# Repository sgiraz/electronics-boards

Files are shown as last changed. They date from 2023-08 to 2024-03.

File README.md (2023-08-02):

Electronics Boards
==================

This is the `electronics-boards` repository, containing all the electronic boards developed for study and DIY purposes.

Each board has an own folder where there are schematic, layout, firmware, simulations, documents, photos, configuration files, etc.

The board folders follow these rules:
- foldername **name of the board** 
- admitted subfolders:
   - **docs** folder contains documents
      - **datasheet** folder contains useful datasheet
      - **manuals** folder contains reference manual
   - **output** folder contains files for the production of the PCB and board (Gerber files, BOM, PCB Notes, etc.)
   - **kicad** folder contains the KiCad project
   - **pics** folder contains useful photos and videos of pcb, board, setup
   - **sw** folder contains the firmware useful for the board (test, normal operation, etc)
   
Note: folders and files must be named in lowercase

## Git LFS remark
This repository exploits the Git Large File Support ([LFS][1]) to handle the binary files.
To download the binary files, follow the GitHub [instructions][2]. To configure Git LFS, follow these [instructions][3].

[1]: https://git-lfs.github.com/
[2]: https://help.github.com/articles/installing-git-large-file-storage/
[3]: https://help.github.com/en/github/managing-large-files/configuring-git-large-file-storage

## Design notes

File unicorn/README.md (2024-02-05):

# The Unicorn Board

## Overview

The Unicorn Board, designed by Simone Girardi in 2022, is a compact, Arduino-like programmable board. It's equipped with service LEDs for TX and RX, making it a versatile tool for various microcontroller projects.

Unicorn Board

## Features

- **ATmega328P Microcontroller**: Powers your projects.
- **16MHz Crystal Oscillator**: Provides a stable clock signal.
- **Input Voltage**: Accepts an external power supply ranging from 7V to 12V.
- **7805 Voltage Regulator**: Ensures a steady 5V supply to the microcontroller and other components.
- **TX and RX LEDs**: Offer visual feedback for data transmission and reception.
- **ISP Header**: Facilitates easy programming.
- **Reset Button**: Allows for easy resetting.

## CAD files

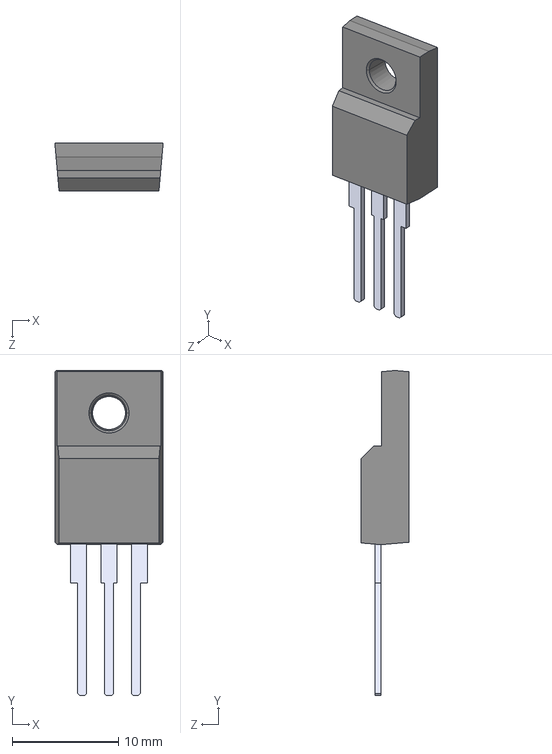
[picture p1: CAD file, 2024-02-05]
unicorn/kicad/components/L7805/L7805.step
10.2 x 30.6 x 4.50 mm

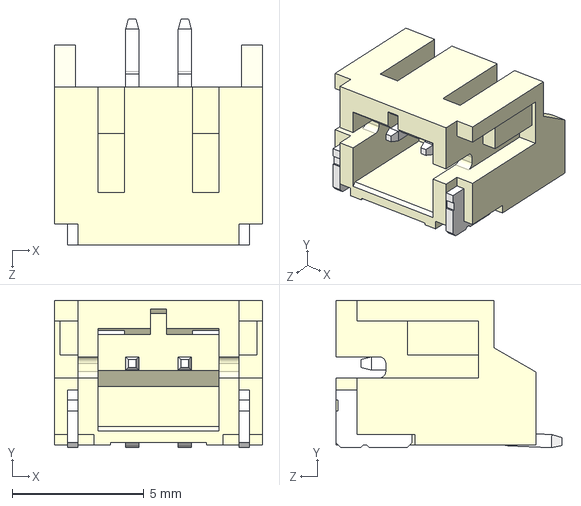
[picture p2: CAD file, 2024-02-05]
unicorn/kicad/components/S2B_PH_SM4_TB/S2B-PH-SM4-TB.step
7.90 x 5.60 x 8.60 mm

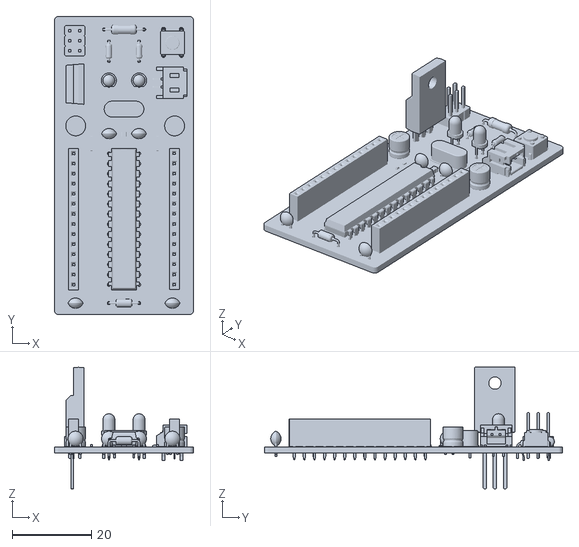
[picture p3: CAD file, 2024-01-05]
unicorn/unicorn.stl
35.0 x 75.0 x 30.6

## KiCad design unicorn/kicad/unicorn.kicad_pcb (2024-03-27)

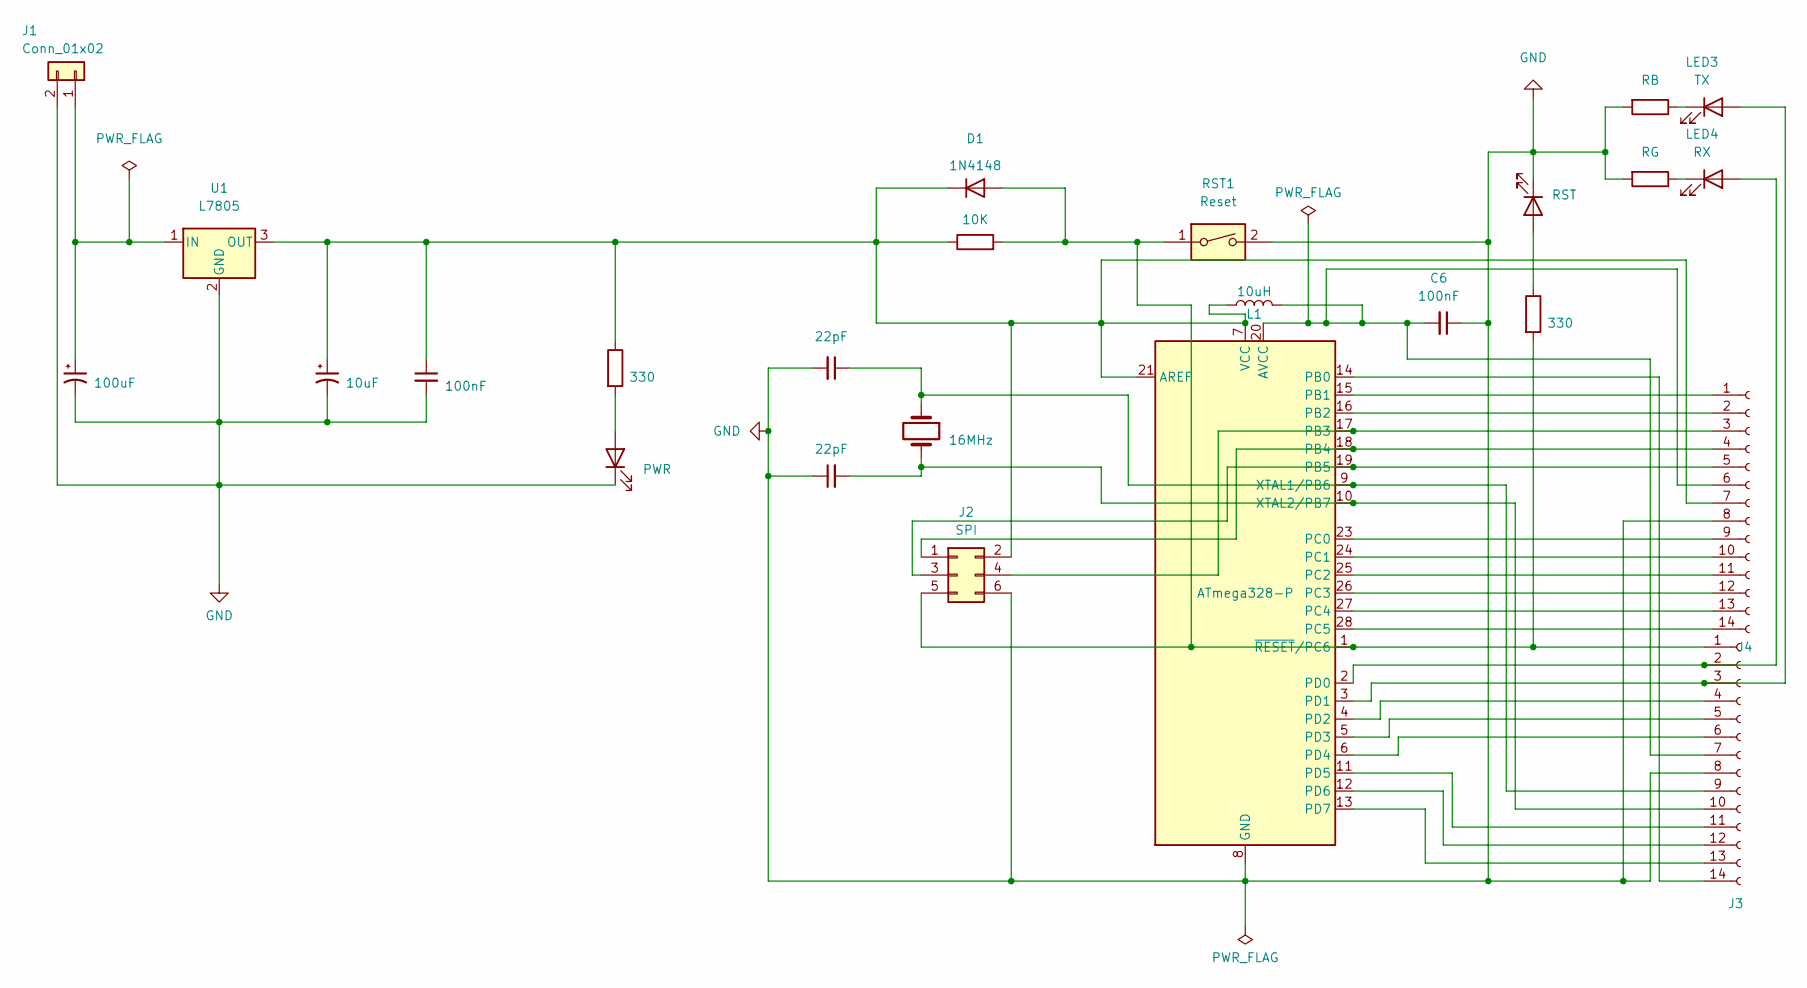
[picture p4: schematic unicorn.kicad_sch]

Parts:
C1: 100uF; CP_Radial_D5.0mm_P2.00mm
C2: 10uF; CP_Radial_D5.0mm_P2.00mm
C3, C6: 100nF; C_Disc_D3.8mm_W2.6mm_P2.50mm
C4, C5: 22pF; C_Disc_D3.8mm_W2.6mm_P2.50mm
Crystal1: 16MHz; Crystal_HC49-4H_Vertical
D1: 1N4148; D_DO-35_SOD27_P7.62mm_Horizontal
J1: Conn_01x02; JST_S2B-PH-SM4-TB
J2: SPI; PinHeader_2x03_P2.54mm_Vertical
J3, J4: Conn_01x14_Female; PinSocket_1x14_P2.54mm_Vertical
L1: 10uH; L_0805_2012Metric_Pad1.05x1.20mm_HandSolder
LED1: PWR; LED_D3.0mm
LED2: RST; LED_D3.0mm
LED3: TX; LED_0402_1005Metric
LED4: RX; LED_0402_1005Metric
R1, R3: 330; R_Axial_DIN0204_L3.6mm_D1.6mm_P5.08mm_Horizontal
R2: 10K; R_Axial_DIN0207_L6.3mm_D2.5mm_P10.16mm_Horizontal
R4: RB; R_0402_1005Metric
R5: RG; R_0402_1005Metric
RST1: Reset; SW_PUSH_6mm
U1: L7805; TO255P1020X450X2000-3
U2: ATmega328-P; DIP-28_W7.62mm

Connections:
GND: C1.2, C2.2, C3.2, C4.2, C5.1, C6.1, J1.2, J2.6, J3.8, J4.8, LED1.1 (K), LED2.1 (K), R4.2, R5.2, RST1.2, U1.2 (GND), U2.8 (GND), U2.22 (GND)
unnamed: D1.2 (A), J2.5, J3.1, R2.2, R3.2, RST1.1, U2.1 (~RESET/PC6)
unnamed: C2.1, C3.1, D1.1 (K), J2.2, J4.7, L1.1, R1.1, R2.1, U1.3 (OUT), U2.7 (VCC), U2.21 (AREF)
unnamed: C1.1, J1.1, U1.1 (IN)
unnamed: J2.1, J4.4, U2.18 (PB4)
unnamed: J2.3, J4.5, U2.19 (PB5)
unnamed: J2.4, J4.3, U2.17 (PB3)
unnamed: J3.2, LED4.2 (A), U2.2 (PD0)
unnamed: J3.3, LED3.2 (A), U2.3 (PD1)
unnamed: J3.4, U2.4 (PD2)
unnamed: J3.5, U2.5 (PD3)
unnamed: J3.6, U2.6 (PD4)
unnamed: C6.2, J3.7, J4.6, L1.2, U2.20 (AVCC)
unnamed: C4.1, Crystal1.1, J3.9, U2.9 (XTAL1/PB6)
unnamed: C5.2, Crystal1.2, J3.10, U2.10 (XTAL2/PB7)
unnamed: J3.11, U2.11 (PD5)
unnamed: J3.12, U2.12 (PD6)
unnamed: J3.13, U2.13 (PD7)
unnamed: J3.14, U2.14 (PB0)
unnamed: J4.1, U2.15 (PB1)
unnamed: J4.2, U2.16 (PB2)
unnamed: J4.9, U2.23 (PC0)
unnamed: J4.10, U2.24 (PC1)
unnamed: J4.11, U2.25 (PC2)
unnamed: J4.12, U2.26 (PC3)
unnamed: J4.13, U2.27 (PC4)
unnamed: J4.14, U2.28 (PC5)
unnamed: LED1.2 (A), R1.2
unnamed: LED2.2 (A), R3.1
unnamed: LED3.1 (K), R4.1
unnamed: LED4.1 (K), R5.1

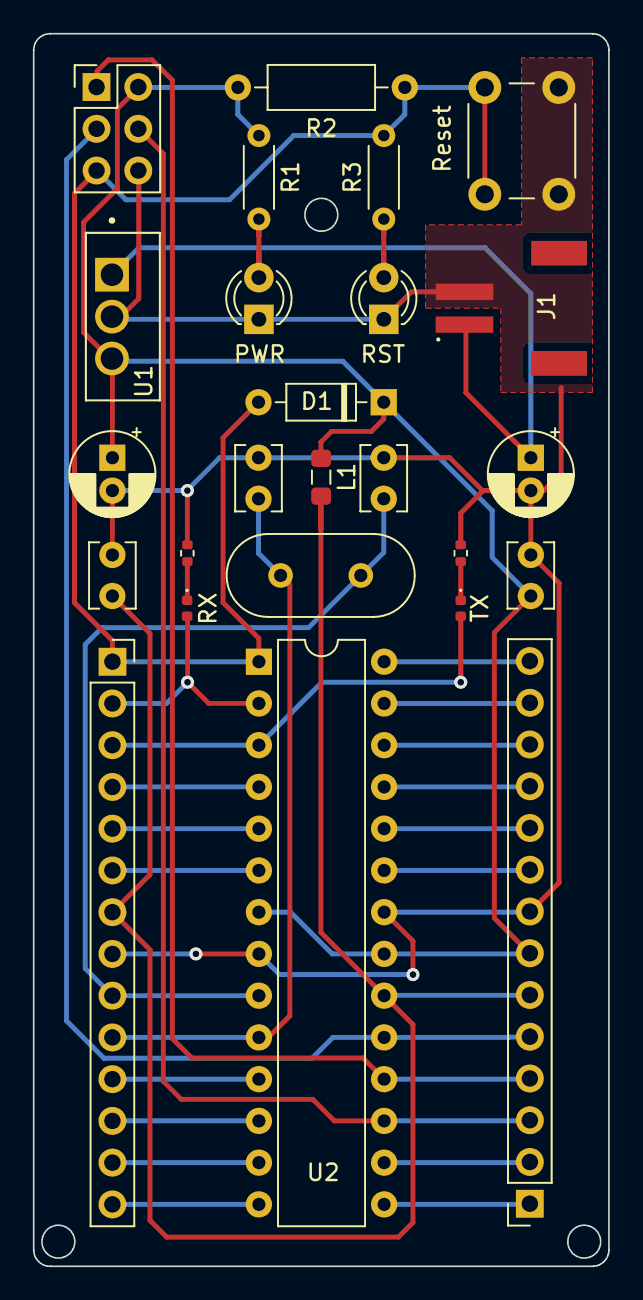
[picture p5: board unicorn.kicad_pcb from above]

Board: 2 copper layers, 35.0 x 75.0 mm, 25 parts (0 on the bottom side), 31 nets.

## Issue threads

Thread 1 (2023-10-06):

Unicorn: Add fixing holes

sgiraz, 2023-10-06:
### Task description

For a simpler mounting we have to create a fixing holes directly on the board.

### Definition of Done

- [ ] holes done and projects updated

sgiraz, 2024-03-03:
Mounting hole applied w/ a diameter M2:

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

>[!Important]
>Before submit a new build of the unicorn board we have to look for the proper screws (see https://it.rs-online.com/web/c/ferramenta/viti-e-bulloni/viti-metriche/)

sgiraz, 2024-03-03:
/remind 3rd March 6:03 PM try to cancel me

sgiraz, 2024-03-03:
/remind 3 March 6:16 try to delete me

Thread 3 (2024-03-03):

Unicorn-Micro – Define the HW requirements

sgiraz, 2024-03-03:
### Task description

We want to evaluate the possibility build a new low-power compact board to control a LED lamp over Bluetooth and/or WiFi.
The board must be powered by battery.

### Definition of Done

- [ ] HW Requirements are well defined

sgiraz, 2024-03-03:
### ❓ Some Queestions

1. How many batteries?
2. Which micro-controller?
3. What are the functional requirements?
4. Do we have to develop an adapter-board for programming?

### ❌ Absolutely to avoid
- No LEDs on board
- No Variable voltage regulator on board
- No more than 6 GPIOs Exposed to the user (maybe only the one for programming?)

### ✅ Absolutely to have
- USB-C connector for powering and charging (and programming?)
- All the components must be SMD
- Battery connector or +/- holes for soldering the battery wires

---

I want to drop here just a couple of info/links found on the web:

We could power the microcontrolled w/ a 3.7 LiPo:
- https://forum.arduino.cc/t/atmega328-powered-by-3-7v-lipo/84931

Todo this we'd need for a Step-Up Power Module integrated on our PCB:
- https://en.wikipedia.org/wiki/Boost_converter
- [ANGEEK-0-9-5V-Step-Up-Voltage-Converter][1]

[1]: https://www.amazon.it/ANGEEK-0-9-5V-Step-Up-Voltage-Converter/dp/B07ZDJPMPJ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

sgiraz, 2024-03-03:
/remind 8th April 2024 Let's start this activity!

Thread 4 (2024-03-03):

Unicorn-Micro – Define the SW requirements

sgiraz, 2024-03-03:
### Task description

Following up on #3, let's identify the key functionalities for the new boards.

### Definition of Done

- [ ] SW requirements are well defined

sgiraz, 2024-03-03:
Be able to measure the Battery Voltage:
- https://www.youtube.com/watch?v=hixEGmf1y5c

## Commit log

2023-08-03 First commit: - add unicorn board - add gitignore - add datasheets
    [unicorn.kicad_pcb, unicorn.kicad_sch]
2023-08-04 update pcb: - add relative path to step file for L7805 component
    [L7805.step, unicorn.kicad_pcb]
2023-08-04 add fp anch sym table settings and fix the projects
    [unicorn.kicad_pcb, unicorn.kicad_sch]
2023-08-08 add step file of the unicorn board
2023-08-08 unicorn: remove step and add stl
    [unicorn.stl]
2024-01-05 Unicorn - Feat/fix components (#2)
    * replace power connector
    - still need to redo routing
    * fix routing + replace power connector with the right one
    * add jst connector + update step file
    [S2B-PH-SM4-TB.step, unicorn.kicad_pcb, unicorn.kicad_sch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]
2024-02-05 update unicorn board layout - minor improvements to the project footprints
    [unicorn.kicad_pcb, unicorn.kicad_sch]
2024-02-05 update img
    [unicorn.kicad_pcb]
2024-02-05 folder reorganization
    [L7805.step, S2B-PH-SM4-TB.step, unicorn.kicad_pcb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]
2024-03-03 Add mounting holes
    [unicorn.kicad_pcb]
2024-03-27 Update project to KiCad 8.0
    [unicorn.kicad_pcb, unicorn.kicad_sch]
